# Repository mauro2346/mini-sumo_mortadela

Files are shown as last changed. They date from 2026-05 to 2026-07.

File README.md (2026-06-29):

OK, basicamente este repositorio contiene todo el codigo, pcb y diseño 3D para un robot minisumo de competencias.
La placa fue diseñada con kicad y sus componentes tanto normales como SMD,
un arduino nano, el driver de los motores, las borneras para conectar los mismos y pineras para conectar los sensores infrarrojos como de ultra sonido.
el codigo ya esta listo para correr en un arduino nano con sus pines pmw para los motores y siguiendo todas las reglas del reglamento nacional.
y el diseño 3D esta listo para imprimirse con las medidas exactas 10x10cm, suficiente espacio dentro para colocar los componentes, un techo opcional prar colocar
y un diseño distintivo del pokemon caterpie en pixel art en la parte frontal del mismo

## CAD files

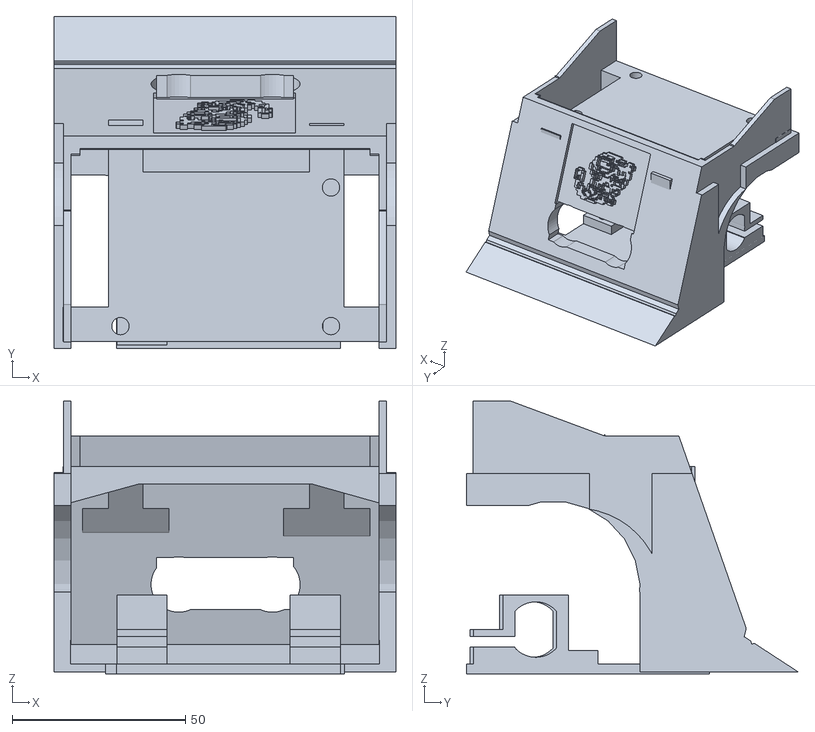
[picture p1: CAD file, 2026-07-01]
Diseño3D/Copy of minisumomortadela.stl
98.7 x 95.9 x 78.7

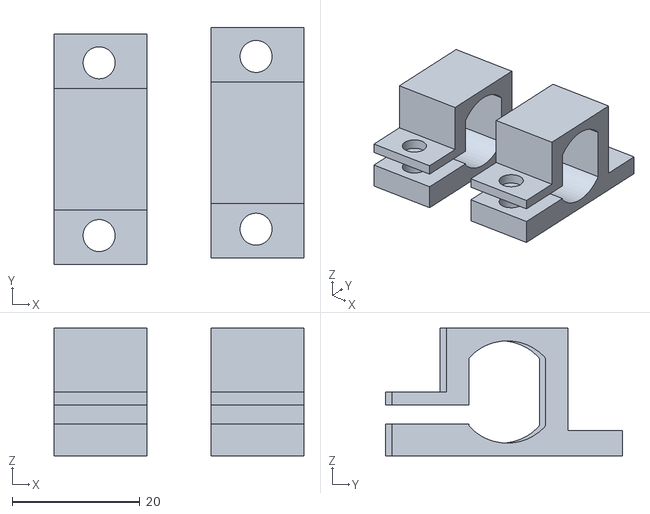
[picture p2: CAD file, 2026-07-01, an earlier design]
Diseño3D/Copy of minisumomortadela (2).stl
39.1 x 37.0 x 20.0

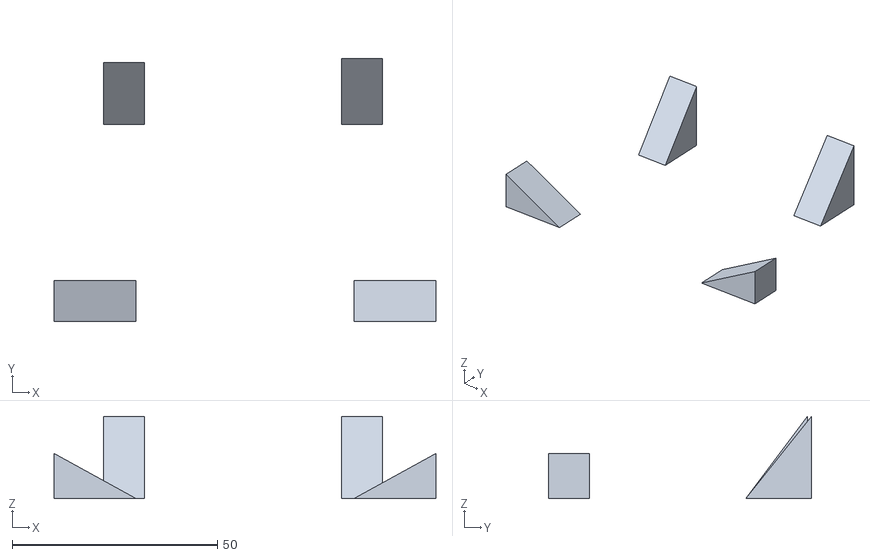
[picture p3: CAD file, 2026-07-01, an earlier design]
Diseño3D/Copy of minisumomortadela (3).stl
93.0 x 64.0 x 20.0

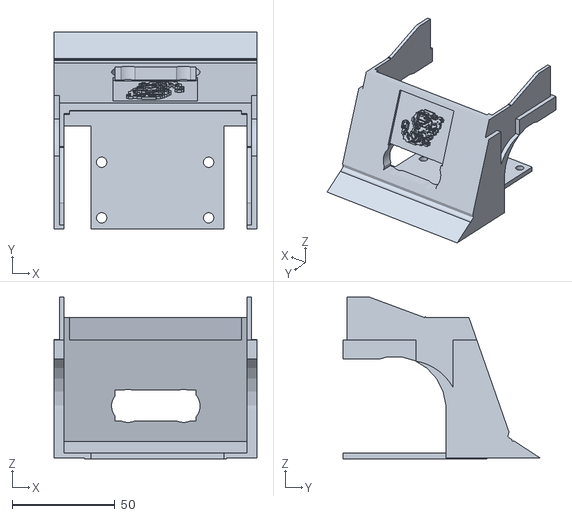
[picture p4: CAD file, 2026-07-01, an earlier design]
Diseño3D/Copy of minisumomortadela (1).stl
98.7 x 95.9 x 78.7

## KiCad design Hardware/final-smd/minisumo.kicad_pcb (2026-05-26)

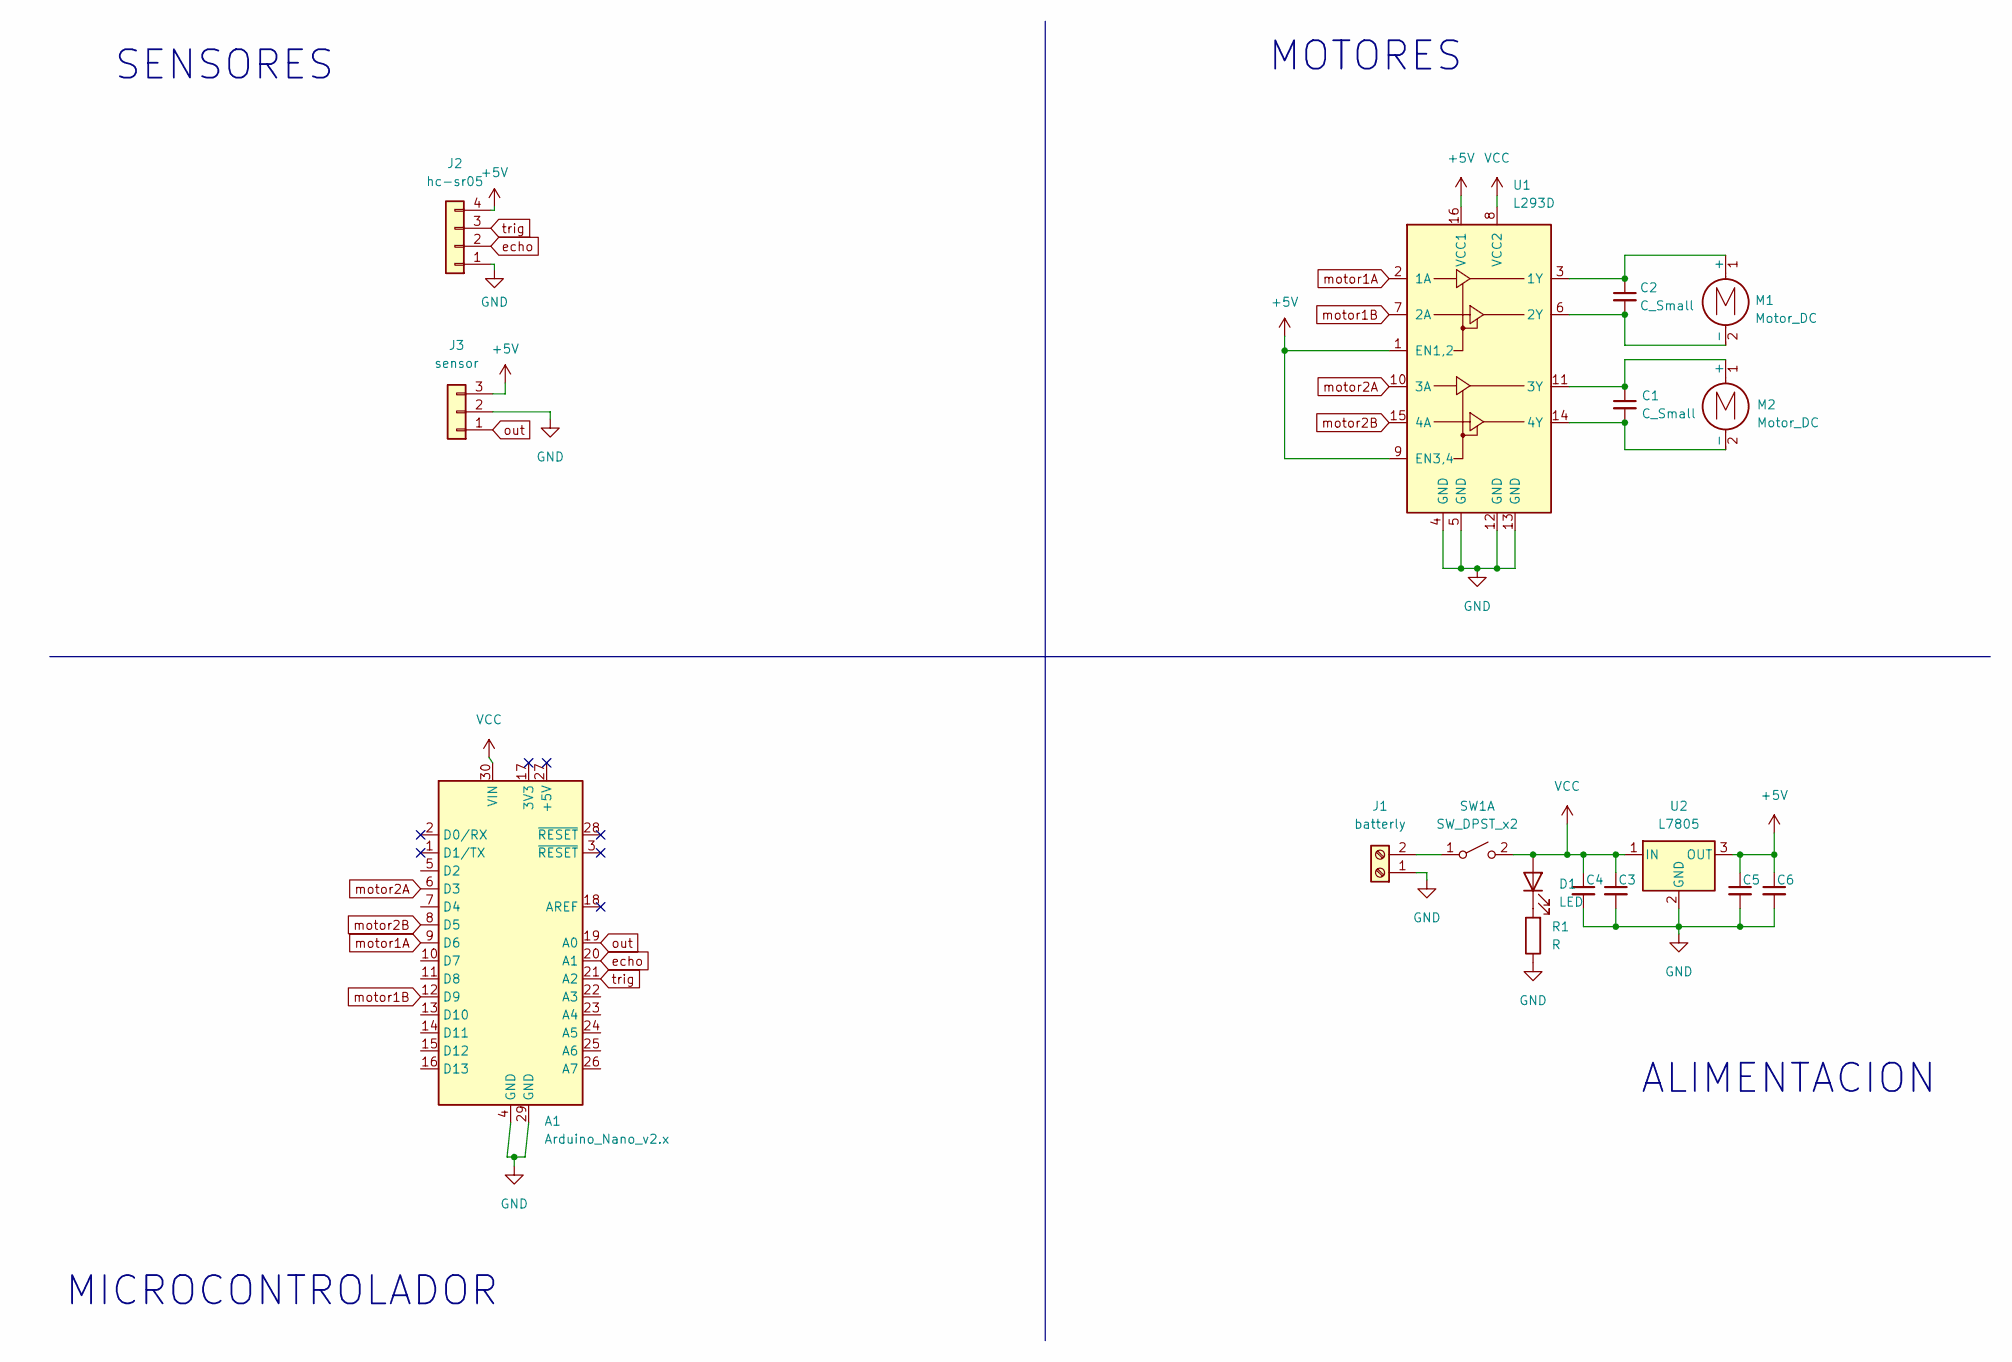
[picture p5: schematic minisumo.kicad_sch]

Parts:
A1: Arduino_Nano_v2.x; arduino_nano_header
C1, C2, C3, C4, C5, C6: C_Small; C_0805_2012Metric
D1: LED; led_5mm_red
J1: batterly; BORNERA2_AZUL
J2: hc-sr05; pin_strip_4
J3: sensor; Pin_Header_3
M1, M2: Motor_DC; BORNERA2_AZUL
R1: R; R_0805_2012Metric
SW1: SW_DPST_x2; Cable-doble_THT-switch
U1: L293D; DIP880W50P254L2000H510Q16
U2: L7805; TO-263-3_TabPin2

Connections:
+5V: C5.1, C6.1, J2.4, J3.3, U1.1 (EN1,2), U1.9 (EN3,4), U1.16 (VCC1), U2.3 (OUT)
GND: A1.4 (GND), A1.29 (GND), C3.2, C4.2, C5.2, C6.2, J1.1, J2.1, J3.2, R1.1, U1.4 (GND), U1.5 (GND), U1.12 (GND), U1.13 (GND), U2.2 (GND)
unnamed: D1.1 (K), R1.2
unnamed: J1.2, SW1.1 (A)
unnamed: C2.1, M1.1 (+), U1.3 (1Y)
unnamed: C2.2, M1.2 (-), U1.6 (2Y)
unnamed: C1.1, M2.1 (+), U1.11 (3Y)
unnamed: C1.2, M2.2 (-), U1.14 (4Y)
VCC: A1.30 (VIN), C3.1, C4.1, D1.2 (A), SW1.2 (B), U1.8 (VCC2), U2.1 (IN)
echo: A1.20 (A1), J2.2
motor1A: A1.9 (D6), U1.2 (1A)
motor1B: A1.12 (D9), U1.7 (2A)
motor2A: A1.6 (D3), U1.10 (3A)
motor2B: A1.8 (D5), U1.15 (4A)
out: A1.19 (A0), J3.1
trig: A1.21 (A2), J2.3

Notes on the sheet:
ALIMENTACION
MOTORES
MICROCONTROLADOR
SENSORES

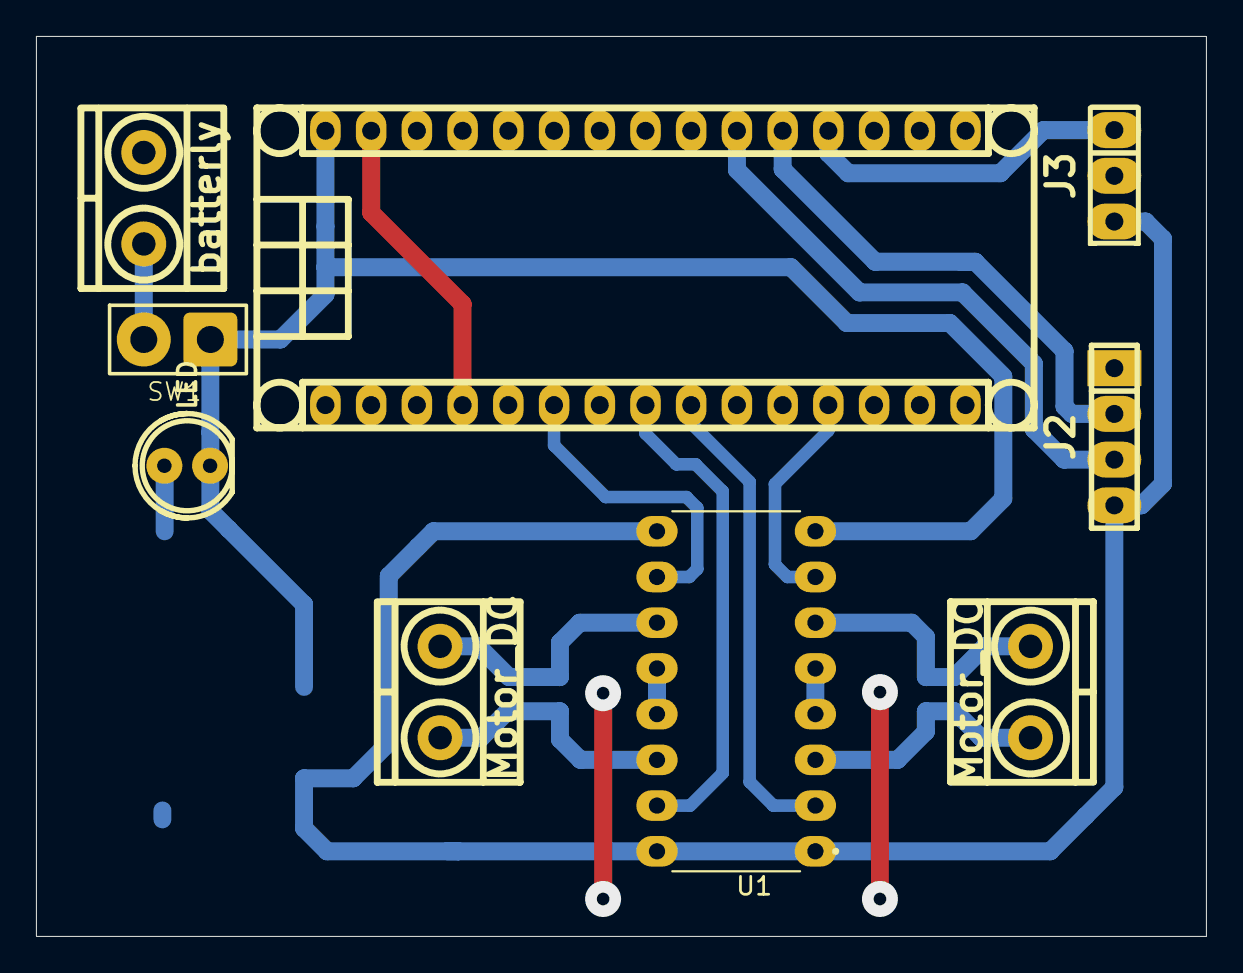
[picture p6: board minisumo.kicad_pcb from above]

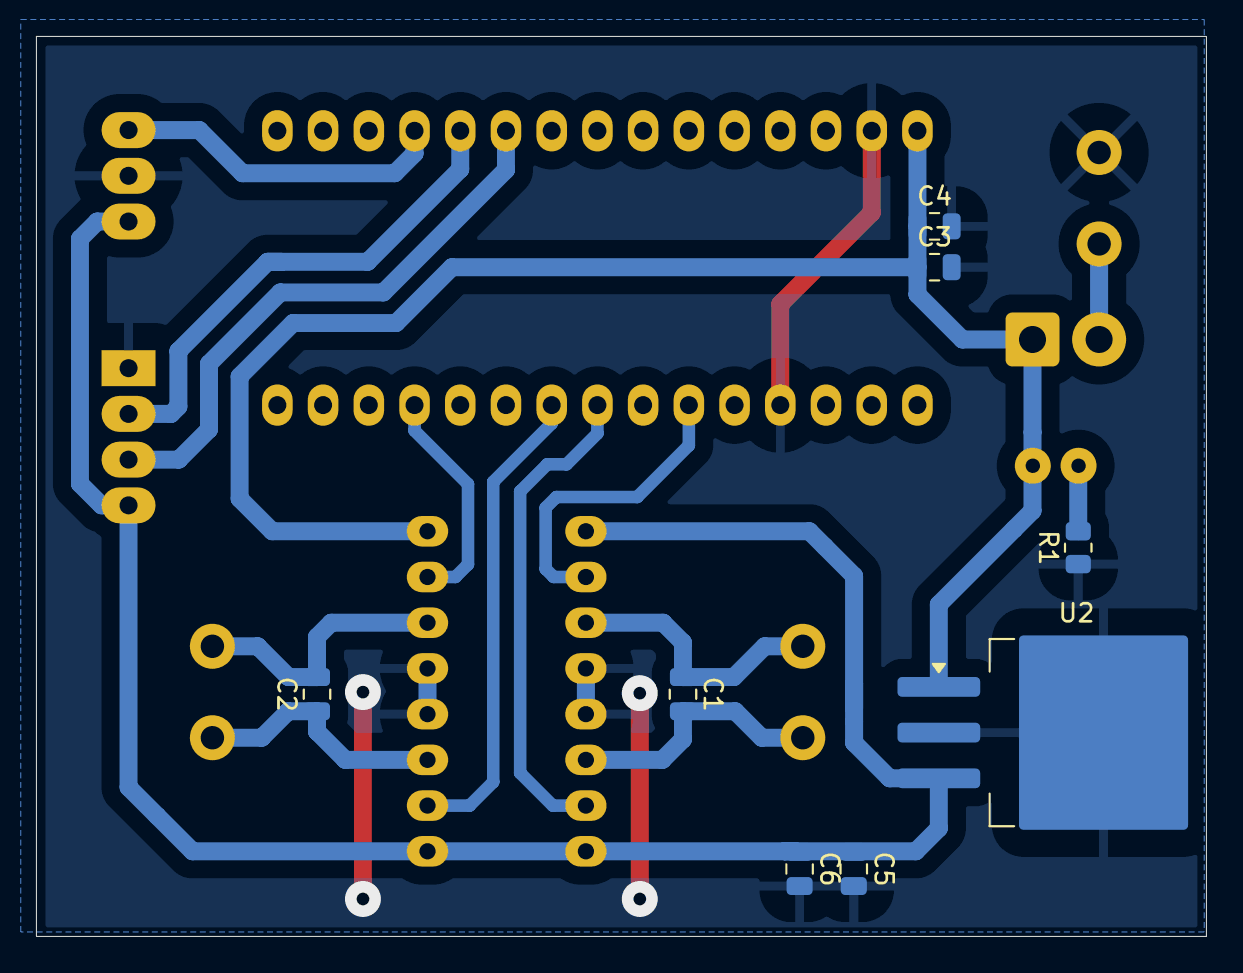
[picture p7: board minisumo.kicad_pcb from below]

Board: 2 copper layers, 65.0 x 50.0 mm, 17 parts (8 on the bottom side), 16 nets.
